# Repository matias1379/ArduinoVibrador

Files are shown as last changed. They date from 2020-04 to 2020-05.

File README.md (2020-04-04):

# Arduino Vibrador

En este repositorio se encuentran los archivos correspondientes al bloque de arduino y vibradores segun colores 

### Carpetas Utiles:

**ArduinoVibrador**: Esta carpeta posee la release 1.0v del codigo. Ha sido simulada y deberia funcionar para recibir un paquete JSON(raspberry) con indicaciones de colores dentro y desempaquetarla para vibrar segun el color

**Codigos Ejemplos**: En esta carpeta estan todos los codigos que nos basamos para entender el funcionamiento de JSON y el modulo HC-05. Estos son codigos con propositos generales

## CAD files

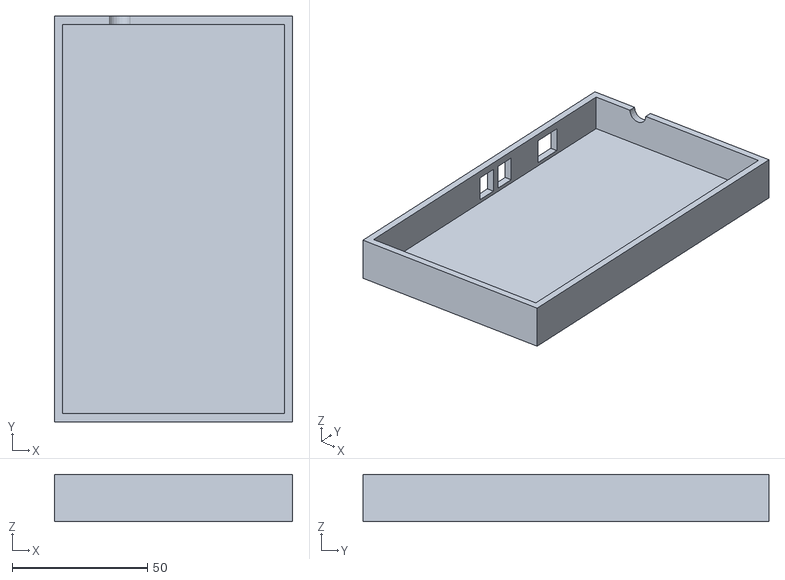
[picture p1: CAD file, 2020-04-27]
CASE_PLACA/Case_placa_parte_1.stl
88.0 x 150.0 x 17.5

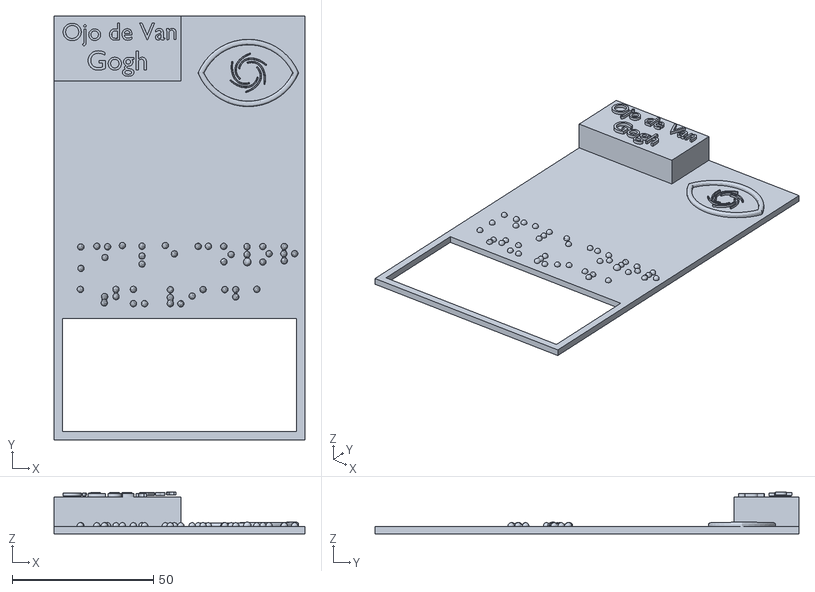
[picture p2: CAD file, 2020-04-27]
CASE_PLACA/Case_placa_parte_2.stl
88.8 x 150.0 x 14.7

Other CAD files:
CASE_PLACA/Case_placa.dwg
CASE_PLACA/CaseTapaConLogo.blend

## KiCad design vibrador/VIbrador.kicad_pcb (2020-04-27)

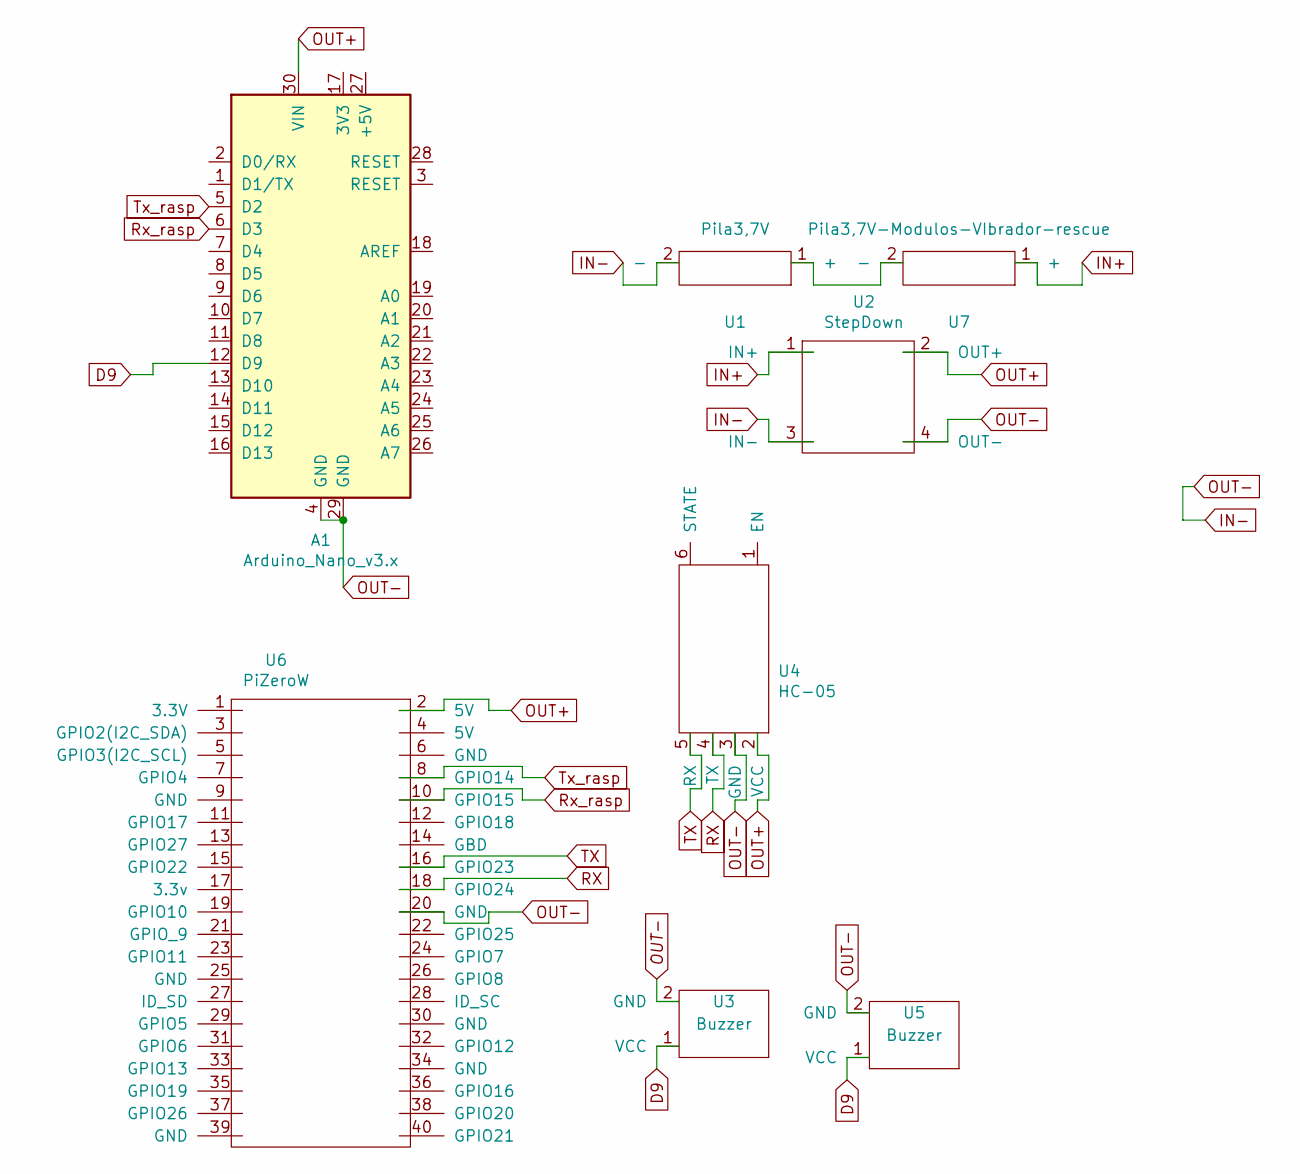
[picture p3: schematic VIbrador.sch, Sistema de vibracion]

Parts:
A1: Arduino_Nano_v3.x; Arduino_Nano
U1: Pila3,7V; Pila de Litio
U2: StepDown
U3, U5: Buzzer; Vibrador
U4: HC-05
U6: PiZeroW; Raspberry_Pi_Zero_Socketed_THT_FaceDown_MountingHoles
U7: Pila3,7V-Modulos-VIbrador-rescue; Pila de Litio

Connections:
D9: A1.12 (D9), U3.1 (VCC), U5.1 (VCC)
IN+: U2.1 (IN+), U7.1 (+)
IN-: A1.4 (GND), A1.29 (GND), U1.2 (-), U2.3 (IN-), U2.4 (OUT-), U3.2 (GND), U4.3 (GND), U5.2 (GND), U6.20 (GND)
unnamed: U1.1 (+), U7.2 (-)
OUT+: A1.30 (VIN), U2.2 (OUT+), U4.2 (VCC), U6.2 (5V)
RX: U4.4 (TX), U6.18 (GPIO24)
Rx_rasp: A1.6 (D3), U6.10 (GPIO15)
TX: U4.5 (RX), U6.16 (GPIO23)
Tx_rasp: A1.5 (D2), U6.8 (GPIO14)

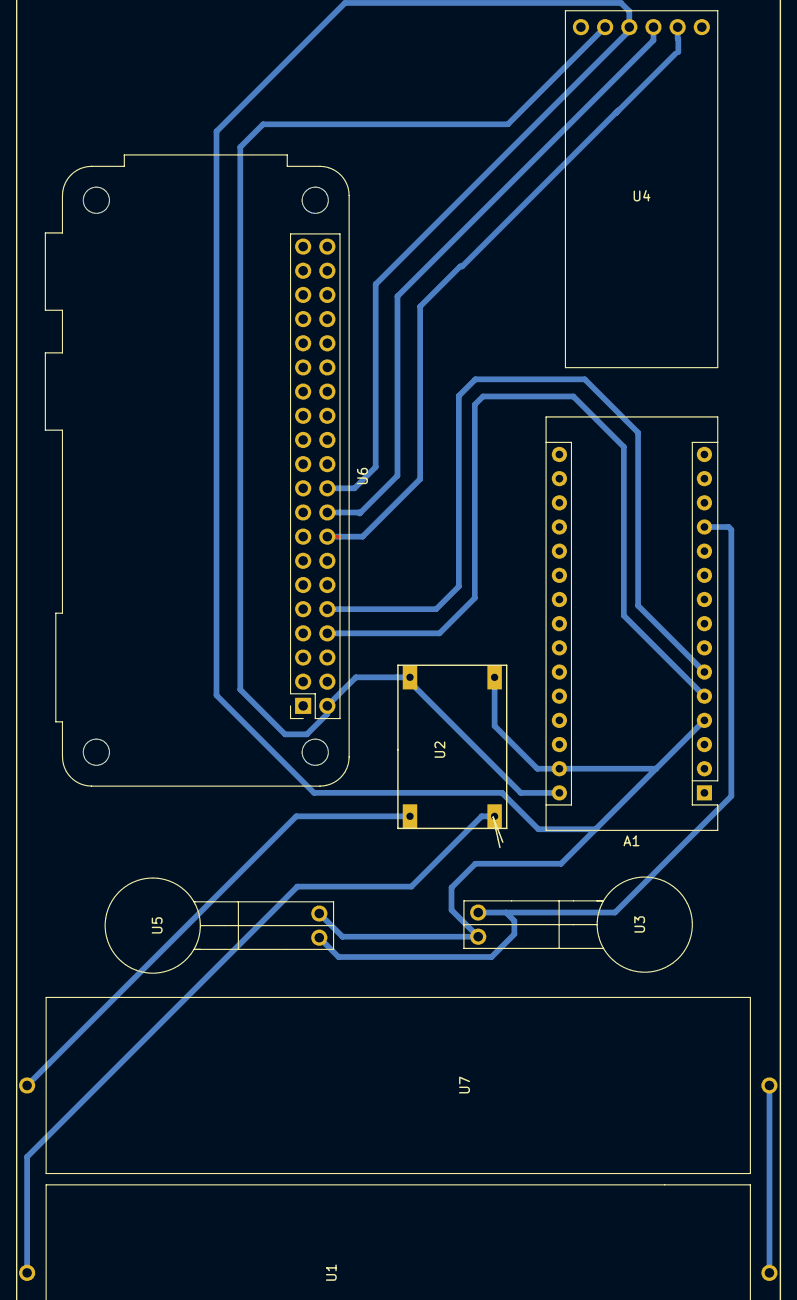
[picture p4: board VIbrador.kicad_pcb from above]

Board: 2 copper layers, 8 parts (0 on the bottom side), 9 nets.

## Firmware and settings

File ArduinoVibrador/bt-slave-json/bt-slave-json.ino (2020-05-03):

#include <ArduinoJson.hpp>        //incluyo librerias de Json
#include <ArduinoJson.h>
#include <SoftwareSerial.h>       //incluyo libreria para cambiar pines de serial
#include "Morse.h"                //incluyo libreria para la vibracion 
SoftwareSerial BTSlave (10, 11);  //pin RX=10, pin TX=11

String str = "";                  //variable que hace el string del json

// Funcion de deserializar Json
String DeserializarJson(String json)  //Devuelve un string y pide el string json
{
    StaticJsonDocument<300> doc;// se crea un objeto llamado doc con 300 bytes de memoria
    DeserializationError error = deserializeJson(doc, json);  //se deserializa el documento y la variable json
    if (error) { return; }                                    // si hay error devolver nada
 
    String color = doc["colour"]; //busco el documento "colour" y guardo lo que contiene 
                //se imprime el contenido de colour, osea rojo
    return color;
}

void setup() {

 Serial.begin(9600);        //Inicializa puerto serie 
 BTSlave.begin(9600);    //Inicializa puerto serie de BT
 
}

void loop() {
  
   while(BTSlave.available()>0){ //mientra llega informacion por BT 
   char caracter=BTSlave.read();    //leo y guardo en caracer
   
     if (caracter != '}'){    //si caracter es distinto a la llave
      str.concat(caracter); //guardo en str cada caracter y formo string
     }
     
     else{
      str.concat('}');//agrego la llave 
      String color = DeserializarJson(str); //deserializo str y guardo en color
      Serial.println(str);
      str = "";
   
       //Se ejecuta la funcion de acuerdo al color
        if(color=="blanco"){
        blanco();
        Serial.println("Está sonando el color: blanco");
        }
                 
        else if(color=="rojo"){
        rojo();
        Serial.println("Está sonando el color: rojo");
        }

        else if(color=="marron"){
        marron();
        Serial.println("Está sonando el color: marron");
        }
                 
        else if(color=="naranja"){
        naranja();
        Serial.println("Está sonando el color: naranja");
        }

        else if(color=="amarillo"){
        amarillo();
        Serial.println("Está sonando el color: amarillo");
        }
                 
        else if(color=="dorado"){
        dorado();
        Serial.println("Está sonando el color: dorado");
        }

        else if(color=="beige"){
        beige();
        Serial.println("Está sonando el color: beige");
        }
                 
        else if(color=="violeta"){
        violeta();
        Serial.println("Está sonando el color: violeta");
        }
      
        else if(color=="rosa"){
        rosa();
        Serial.println("Está sonando el color: rosa");
        }
                 
        else if(color=="purpura"){
        purpura();
        Serial.println("Está sonando el color: purpura");
        }

        else if(color=="verde"){
        verde();
        Serial.println("Está sonando el color: verde");
        }
                 
        else if(color=="azul"){
        azul();
        Serial.println("Está sonando el color: azul");
        }

        else if(color=="cyan"){
        cyan();
        Serial.println("Está sonando el color: cyan");
        }
                 
       else if(color=="plata"){
        plata();
        Serial.println("Está sonando el color: plata");
        }

       else if(color=="gris"){
        gris();
        Serial.println("Está sonando el color: gris");
        }
                 
       else if(color=="negro"){
        negro();
        Serial.println("Está sonando el color: negro");
        }
       Serial.println("***************");
     }
  }  
}

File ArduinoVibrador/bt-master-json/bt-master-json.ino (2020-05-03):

#include <ArduinoJson.hpp>        //incluyo librerias de Json
#include <ArduinoJson.h>
#include <SoftwareSerial.h>       //incluyo libreria para cambiar pines de serial
SoftwareSerial BTMaster (8, 9);  //pin RX=8, pin TX=9
String color;
// Funcion de serializar Json
String SerializarJson()
{
    String json;  
    StaticJsonDocument<300> doc;  // se crea un objeto llamado doc con 300 bytes de memoria
    doc["colour"] = ""+String(color);       //el documento colour tiende valor a rojo
    
    serializeJson(doc, json);     //se serializa el doc y guarda en json
    return json;
}

int str_len =SerializarJson().length()+1;
char charArray[100];

void setup() {

 Serial.begin(9600);        //Inicializa puerto serie 
 BTMaster.begin(9600);    //Inicializa puerto serie de BT
 Serial.println("Parpadee");
}

void loop() {
  
  if(Serial.available()>0){ //Si en el serial hay un dato
     color = Serial.readString(); 
    if(color == "rojo" || color == "violeta"){  //si es 1 lo que leo del serial
       SerializarJson().toCharArray(charArray, 100);    //hago el string json en un char array
       Serial.println("Color:"+String(color));
       Serial.println("***************");
       BTMaster.write(charArray); //escribo en el bt el char array
    }
    
  }
     
}

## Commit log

2020-03-27 Programas de Json y Bt
2020-03-28 Se ordeno repo
    [VIbrador.sch]
2020-04-04 Los codigos finales se colocaron en ArduinoVibrador que seria los que usemos. Los codigos que ayudan a entender el repo y cada una de sus Features estan dentro de CodigosEjemplos
    [VIbrador.sch]
2020-04-04 se borraron archivos duplicados
    [VIbrador.sch]
2020-04-04 se actualizo el readme
2020-04-05 Se ha realizado el PCB
    Se ha cambiado el esquematico de RX y TX siendo ahora RX el D11 y TX el D10. Se hizo la placa ya que estamos consultando con una empresa para Pcb's flexible
    [VIbrador.kicad_pcb, _saved_VIbrador.sch]
2020-04-05 Agregue un buzzer
    [VIbrador.sch, _saved_VIbrador.sch]
2020-04-06 Se agrego informacion al rotulo del pcb
    [VIbrador.sch]
2020-04-06 Se agregó zona de relleno
    [VIbrador.kicad_pcb]
2020-04-09 Se agrego libreria . cpp y .h de morse
    Se creo para cada color un determinado codigo morse y se hizo un programa de prueba
2020-04-09 Se cambio el archivo .cpp a .c
    Se cambio la extension y el codigo para C(no anda todavia)
2020-04-10 Se agrego esquematico de la Pi Zero W
2020-04-11 Se agregaron los PCB de HC-05, pila (falta completar) y vibrador
    Tambien cambie el simbolo de hc-05 ya que le faltaban dos pines
    [VIbrador.kicad_pcb, VIbrador.sch]
2020-04-11 Se actualizo la poscion de la raspberry para conveniencia de la pi camera
    [VIbrador.kicad_pcb]
2020-04-13 PCB con StepDown
    [VIbrador.kicad_pcb, VIbrador.sch]
2020-04-13 Se cambio la extension de.c a .cpp
    Cambiando la extension se logro que ande el programa
2020-04-14 Se finalizo PCB
    Se cambio la huella de pila, y posicion de rx y tx en arduino
    [VIbrador.kicad_pcb, _saved_VIbrador.sch]
2020-04-14 Se guardo el PCB finallizado
    [VIbrador.kicad_pcb, VIbrador.sch, _saved_VIbrador.sch]
2020-04-14 Se unieron IN- Y OUT- ya que los dos son GND de el step down y es lo mismo
    [VIbrador.kicad_pcb, VIbrador.sch]
2020-04-15 Se agregaron las librerias de morse al programa final y sus comparaciones
    Se ha actualizado el programa final
2020-04-24 Se creo la carpeta para el case
    [Case_placa.dwg]
2020-04-24 Se inicio el diseño 3D de el case y se modifico el TX/RX del bt para conectarlo a la raspberry
    [Case_placa.dwg, VIbrador.sch]
2020-04-26 Se termino el case falta hacerle el hueco dela bateria
    [Case_placa.dwg, VIbrador.kicad_pcb]
2020-04-26 Se termino de hacer las cosas en 3D
    Se creo el case que tiene dos stl:
    Case parte 1 es la base donde van las cosas.
    Case parte 2 es la tapa que tiene el logo y el slogan en braille
    [CaseTapaConLogo.blend, Case_placa.dwg, Case_placa_parte_1.stl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]
2020-04-27 Se borro un error
    habia un punto en el aire en el case
    [CaseTapaConLogo.blend, Case_placa_parte_2.stl]
2020-04-27 Correcion de case_placa_parte_1
    El archivo stl estaba desactualizado con respecto a las modificaciones del cad
    [Case_placa_parte_1.stl]
2020-05-03 Se corrigieron errores y agregaron algunos detalles
    Se hizo un programa para que se pueda escribir en el serial un color y se mande al receptor y vibre de acuerdo al color
    [bt-master-json.ino, bt-slave-json.ino]
